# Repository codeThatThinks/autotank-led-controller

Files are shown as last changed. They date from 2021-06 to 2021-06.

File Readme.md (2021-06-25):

# autotank-led-hw

A CANbus-enabled LED and GPIO controller -- PCB design files

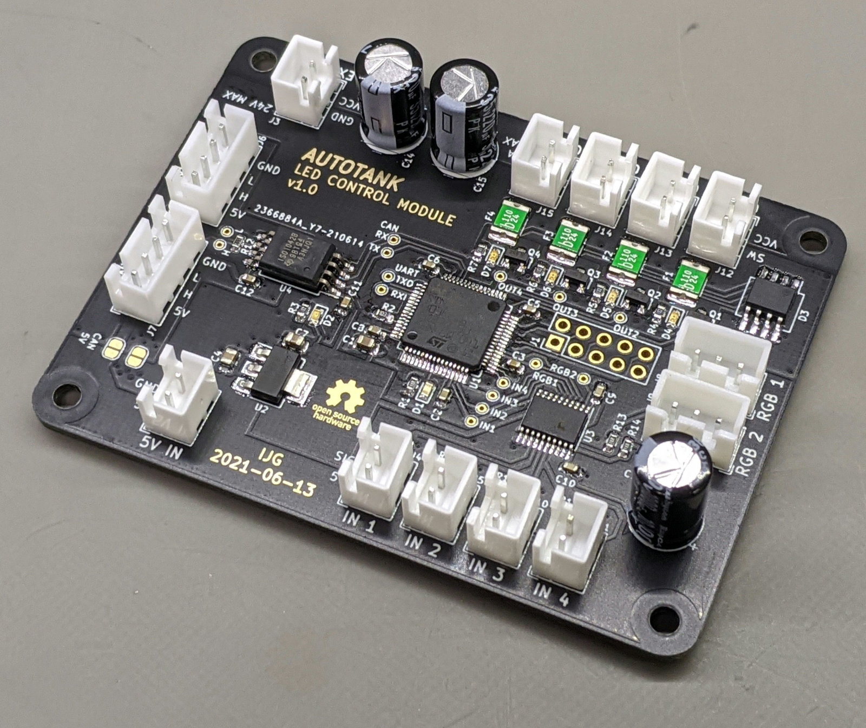
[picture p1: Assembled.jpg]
Assembled PCB


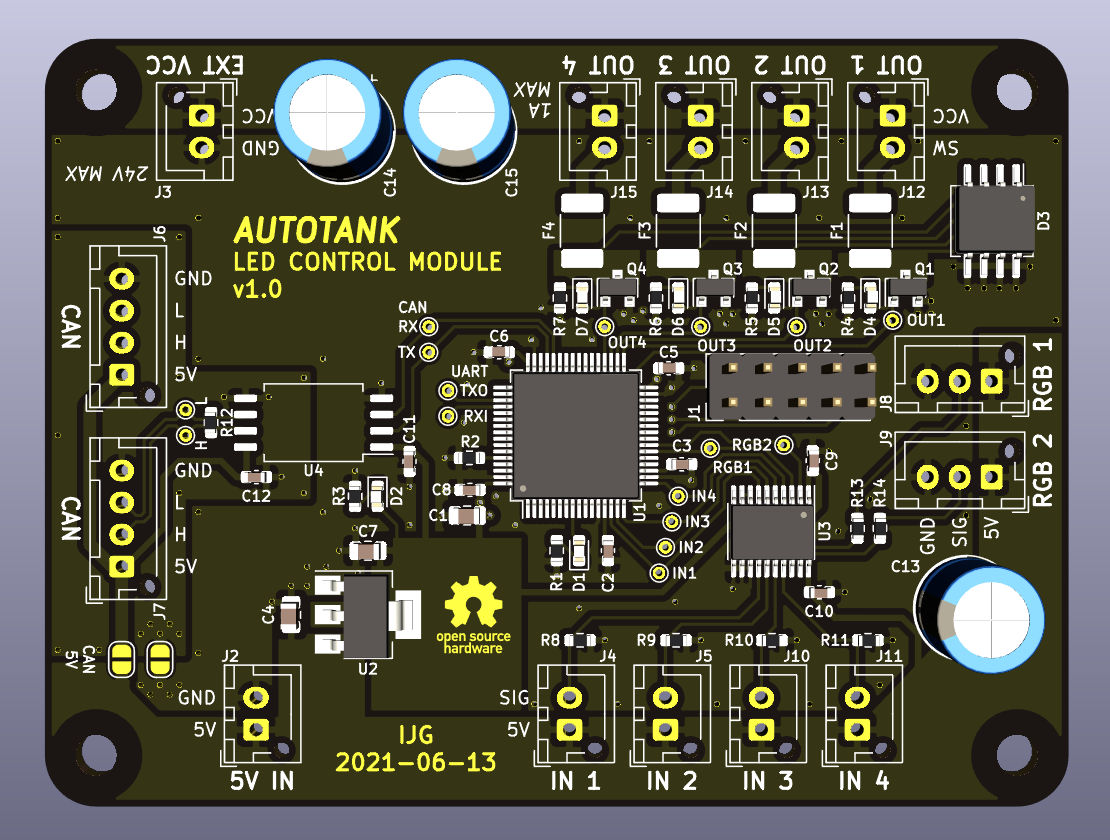
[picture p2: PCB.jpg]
PCB Render


## Theory of Operation

The controller listens for messages on the CANbus and drives two addressable RGB LED strips and four general-purpose open-collector outputs. It also monitors four general-purpose inputs and can send CANbus messages or change outputs in response to events.

The outputs are rated for 1A each and are intended to drive LED lights, such as headlights, tail lights, etc. The inputs are active-high and intended for body sensors and switches, such as a door switch.

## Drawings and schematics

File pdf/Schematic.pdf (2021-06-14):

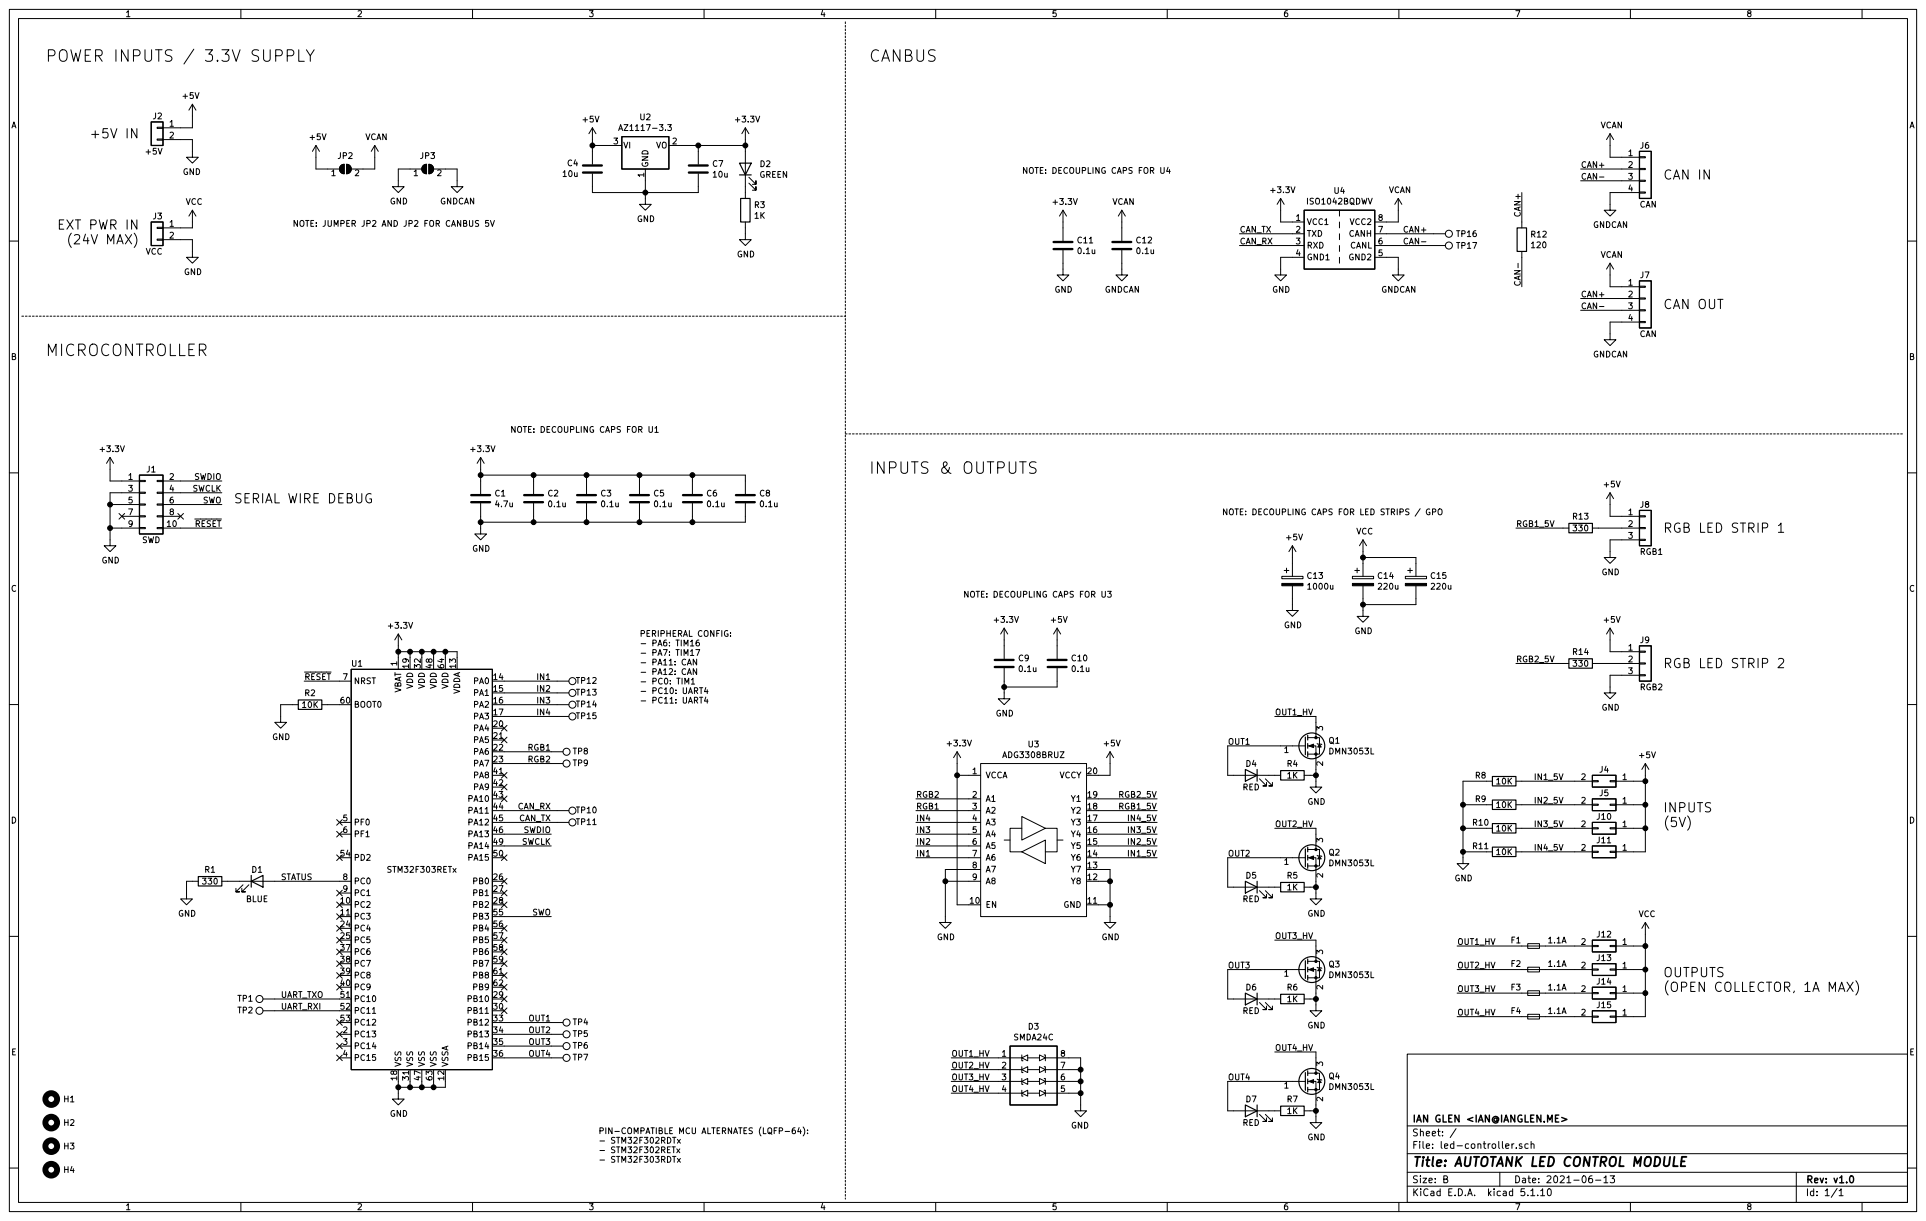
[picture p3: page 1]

NOTE: DECOUPLING CAPS FOR LED STRIPS / GPO POWER INPUTS / 3.3V SUPPLY

NOTE: DECOUPLING CAPS FOR U4 CANBUS
0.1u GND

1 VDD 19 VDD 32 VDD 48 VDD 64 VDDA 13 VSS 18 VSS 31 VSS 47 VSS 63 VSSA 12 U1 STM32F303RETx +3.3V

IAN GLEN <IAN@IANGLEN.ME> GND

File: led-controller.sch Sheet: /
Id: 1/1 Title: AUTOTANK LED CONTROL MODULE

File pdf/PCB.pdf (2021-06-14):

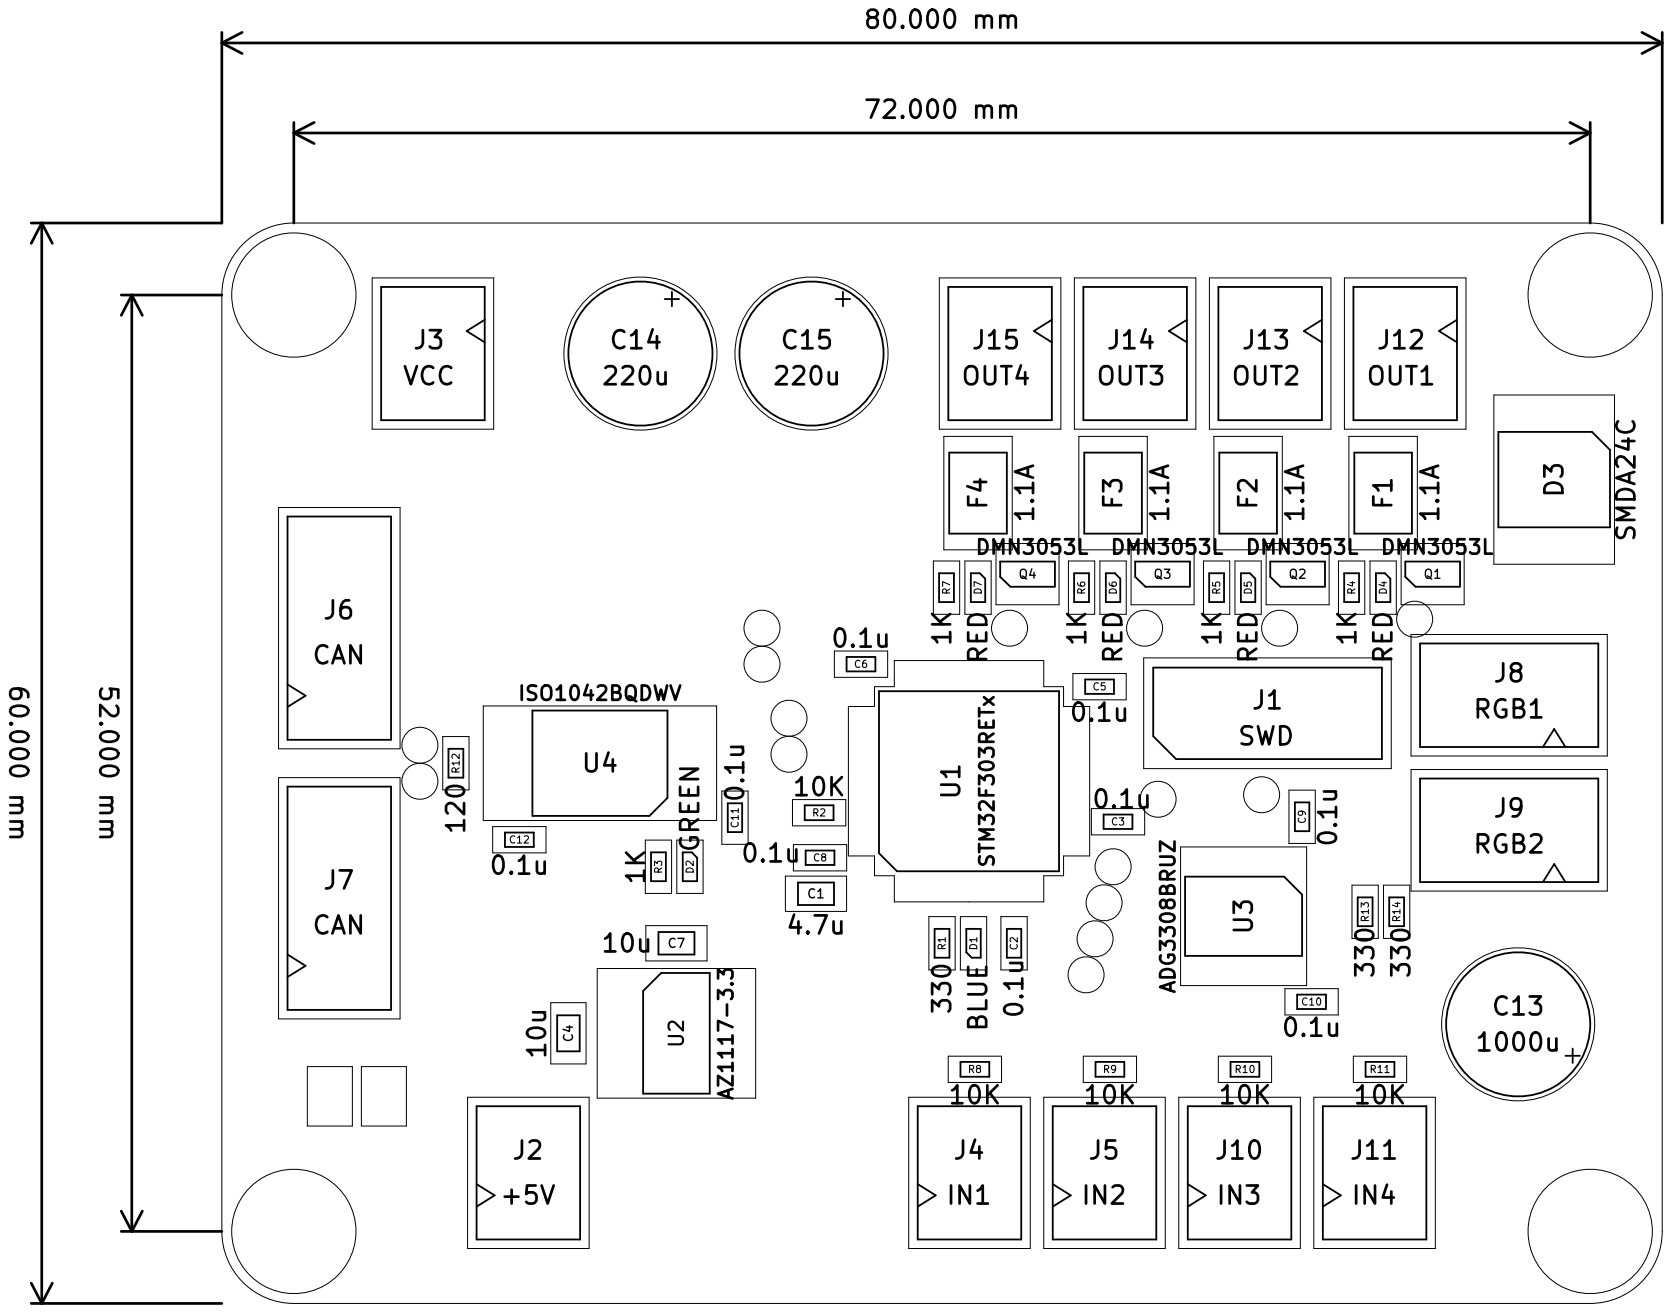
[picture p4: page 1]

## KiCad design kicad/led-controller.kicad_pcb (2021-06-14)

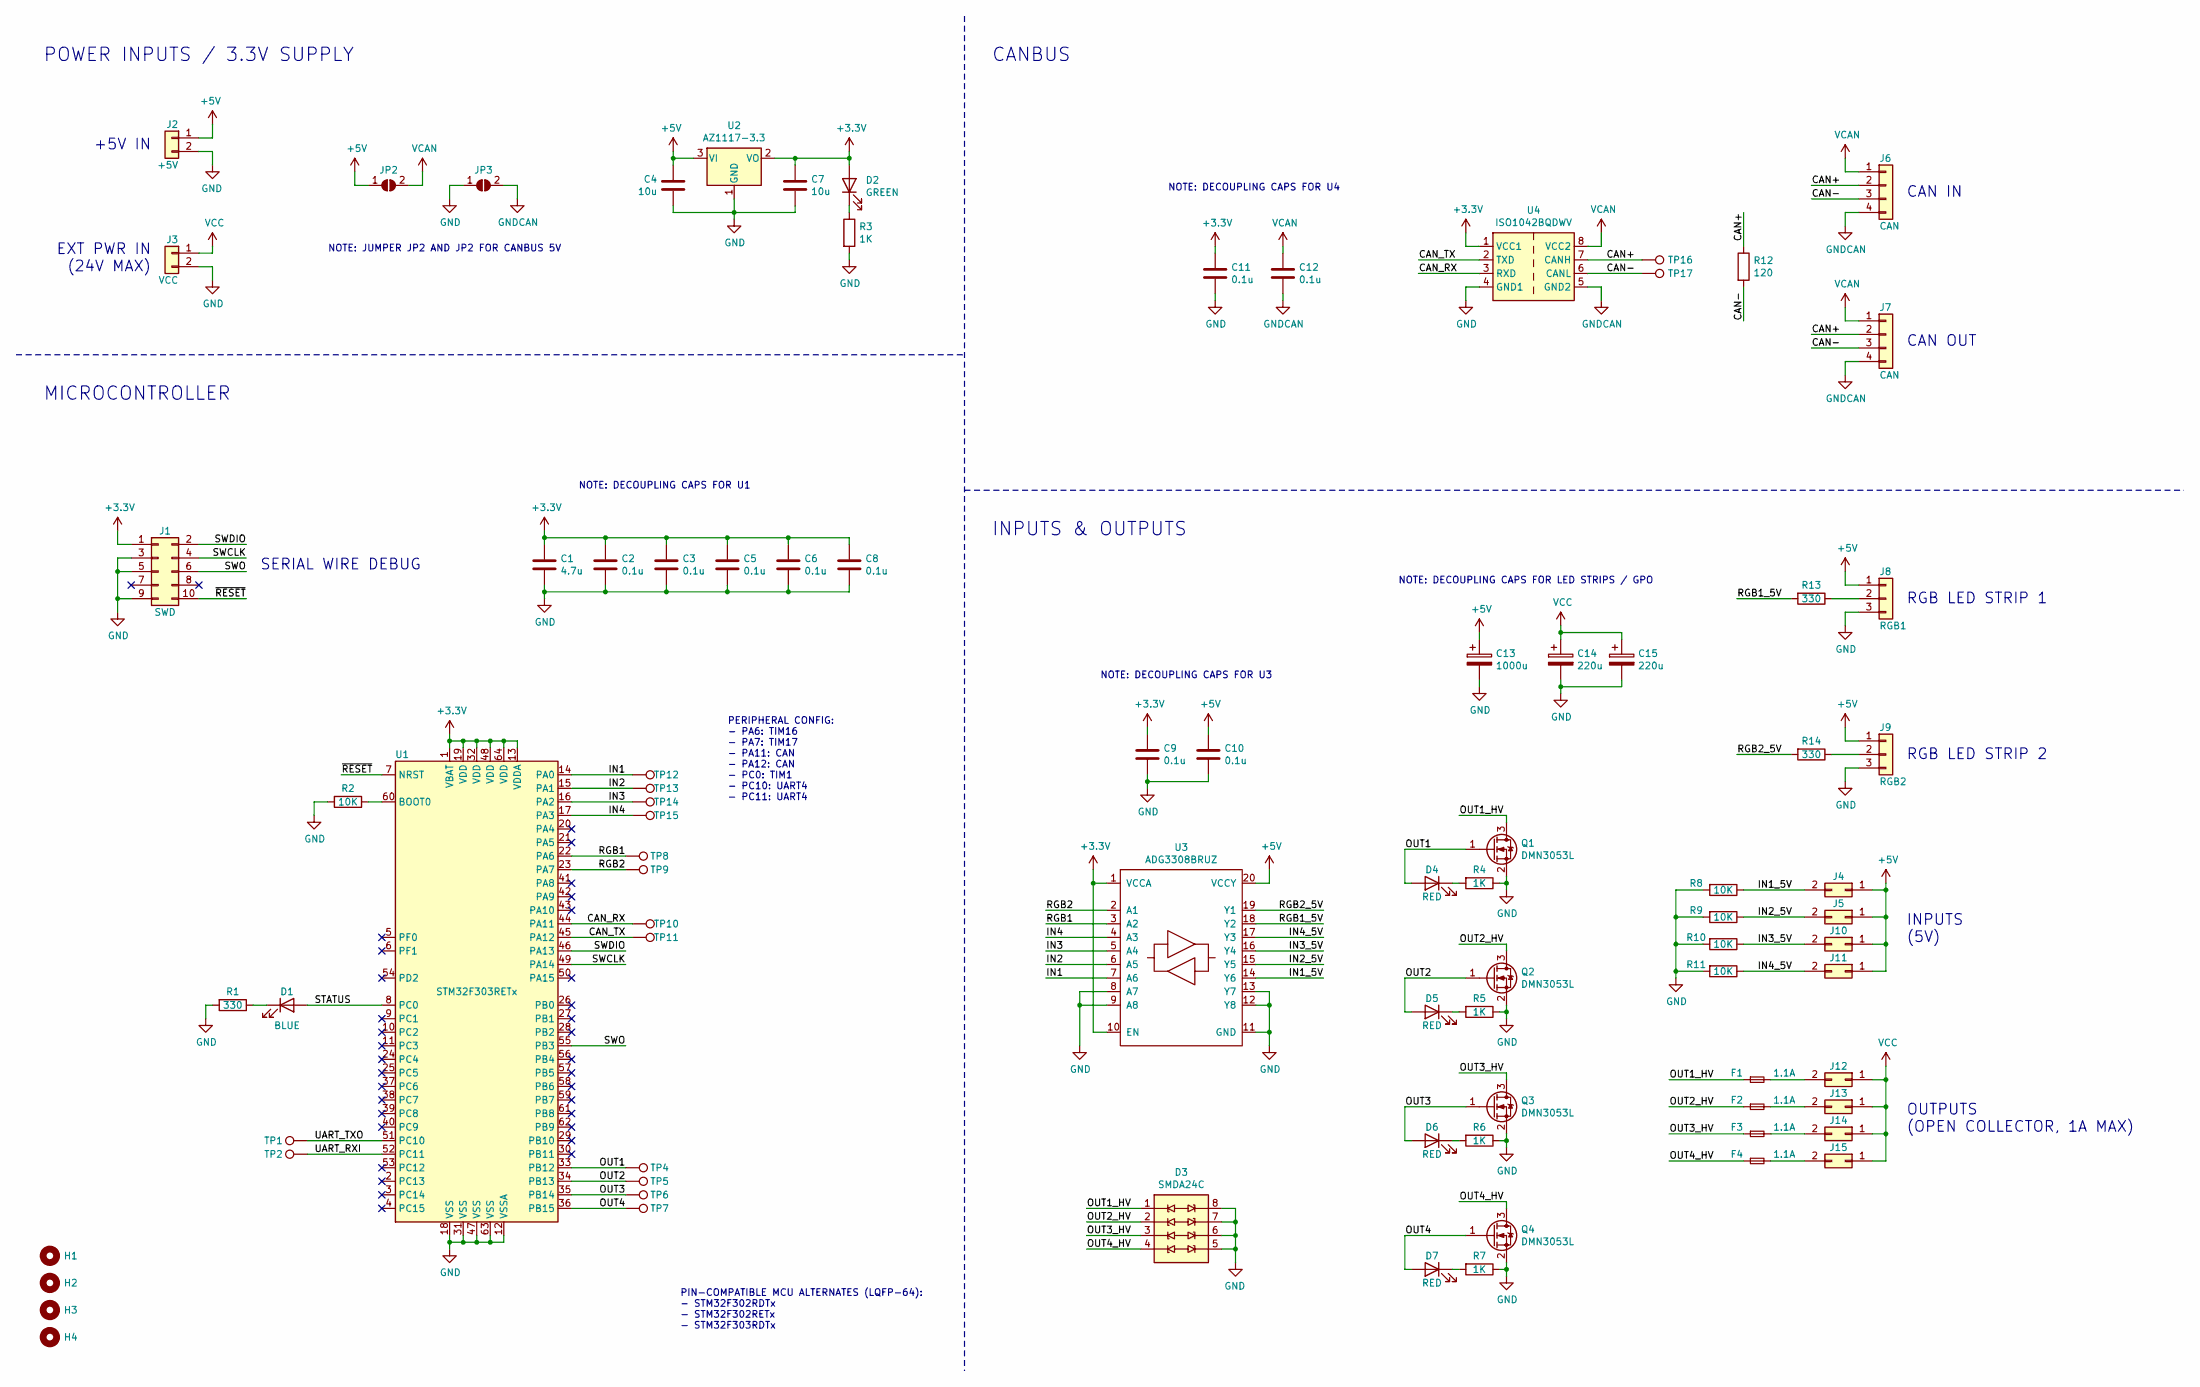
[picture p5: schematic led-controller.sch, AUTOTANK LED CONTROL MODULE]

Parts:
C1: 4.7u; C_0805_2012Metric
C2, C3, C5, C6, C8, C9, C10, C11, C12: 0.1u; C_0603_1608Metric
C4, C7: 10u; C_0805_2012Metric
C13: 1000u; CP_Radial_D8.0mm_P3.50mm
C14, C15: 220u; CP_Radial_D8.0mm_P3.50mm
D1: BLUE; LED_0603_1608Metric
D2: GREEN; LED_0603_1608Metric
D3: SMDA24C; SO-8_5.3x6.2mm_P1.27mm
D4, D5, D6, D7: RED; LED_0603_1608Metric
F1, F2, F3, F4: 1.1A; Fuse_1812_4532Metric_Castellated
H1, H2, H3, H4: MountingHole; MountingHole_3.2mm_M3
J1: SWD; PinHeader_2x05_P2.54mm_Vertical
J2: +5V; JST_XH_B2B-XH-AM_1x02_P2.50mm_Vertical
J3: VCC; JST_XH_B2B-XH-AM_1x02_P2.50mm_Vertical
J4: IN1; JST_XH_B2B-XH-AM_1x02_P2.50mm_Vertical
J5: IN2; JST_XH_B2B-XH-AM_1x02_P2.50mm_Vertical
J6, J7: CAN; JST_XH_B4B-XH-AM_1x04_P2.50mm_Vertical
J8: RGB1; JST_XH_B3B-XH-AM_1x03_P2.50mm_Vertical
J9: RGB2; JST_XH_B3B-XH-AM_1x03_P2.50mm_Vertical
J10: IN3; JST_XH_B2B-XH-AM_1x02_P2.50mm_Vertical
J11: IN4; JST_XH_B2B-XH-AM_1x02_P2.50mm_Vertical
J12: OUT1; JST_XH_B2B-XH-AM_1x02_P2.50mm_Vertical
J13: OUT2; JST_XH_B2B-XH-AM_1x02_P2.50mm_Vertical
J14: OUT3; JST_XH_B2B-XH-AM_1x02_P2.50mm_Vertical
J15: OUT4; JST_XH_B2B-XH-AM_1x02_P2.50mm_Vertical
JP2, JP3: SolderJumper_2_Open; SolderJumper-2_P1.3mm_Open_RoundedPad1.0x1.5mm
Q1, Q2, Q3, Q4: DMN3053L; SOT-23
R1, R13, R14: 330; R_0603_1608Metric
R2, R8, R9, R10, R11: 10K; R_0603_1608Metric
R3, R4, R5, R6, R7: 1K; R_0603_1608Metric
R12: 120; R_0603_1608Metric
TP1: TXO; TestPoint_THTPad_D1.0mm_Drill0.5mm
TP2: RXI; TestPoint_THTPad_D1.0mm_Drill0.5mm
TP4: OUT1; TestPoint_THTPad_D1.0mm_Drill0.5mm
TP5: OUT2; TestPoint_THTPad_D1.0mm_Drill0.5mm
TP6: OUT3; TestPoint_THTPad_D1.0mm_Drill0.5mm
TP7: OUT4; TestPoint_THTPad_D1.0mm_Drill0.5mm
TP8: RGB1; TestPoint_THTPad_D1.0mm_Drill0.5mm
TP9: RGB2; TestPoint_THTPad_D1.0mm_Drill0.5mm
TP10: RX; TestPoint_THTPad_D1.0mm_Drill0.5mm
TP11: TX; TestPoint_THTPad_D1.0mm_Drill0.5mm
TP12: IN1; TestPoint_THTPad_D1.0mm_Drill0.5mm
TP13: IN2; TestPoint_THTPad_D1.0mm_Drill0.5mm
TP14: IN3; TestPoint_THTPad_D1.0mm_Drill0.5mm
TP15: IN4; TestPoint_THTPad_D1.0mm_Drill0.5mm
TP16: H; TestPoint_THTPad_D1.0mm_Drill0.5mm
TP17: L; TestPoint_THTPad_D1.0mm_Drill0.5mm
U1: STM32F303RETx; LQFP-64_10x10mm_P0.5mm
U2: AZ1117-3.3; SOT-223-3_TabPin2
U3: ADG3308BRUZ; TSSOP-20_4.4x6.5mm_P0.65mm
U4: ISO1042BQDWV; SOIC-8_7.5x5.85mm_P1.27mm

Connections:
+3V3: C1.1, C2.1, C3.1, C5.1, C6.1, C7.1, C8.1, C9.1, C11.1, D2.2 (A), J1.1, U1.1 (VBAT), U1.13 (VDDA), U1.19 (VDD), U1.32 (VDD), U1.48 (VDD), U1.64 (VDD), U2.2 (VO), U3.1 (VCCA), U3.10 (EN), U4.1 (VCC1)
+5V: C4.2, C10.1, C13.1, J2.1, J4.1, J5.1, J8.1, J9.1, J10.1, J11.1, JP2.1 (A), U2.3 (VI), U3.20 (VCCY)
/CAN+: J6.2, J7.2, R12.1, TP16.1, U4.7 (CANH)
/CAN-: J6.3, J7.3, R12.2, TP17.1, U4.6 (CANL)
/CAN_RX: TP10.1, U1.44 (PA11), U4.3 (RXD)
/CAN_TX: TP11.1, U1.45 (PA12), U4.2 (TXD)
/IN1: TP12.1, U1.14 (PA0), U3.7 (A6)
/IN1_5V: J4.2, R8.1, U3.14 (Y6)
/IN2: TP13.1, U1.15 (PA1), U3.6 (A5)
/IN2_5V: J5.2, R9.1, U3.15 (Y5)
/IN3: TP14.1, U1.16 (PA2), U3.5 (A4)
/IN3_5V: J10.2, R10.1, U3.16 (Y4)
/IN4: TP15.1, U1.17 (PA3), U3.4 (A3)
/IN4_5V: J11.2, R11.1, U3.17 (Y3)
/OUT1: D4.2 (A), Q1.1 (G), TP4.1, U1.33 (PB12)
/OUT1_HV: D3.1 (TVS1A), F1.1, Q1.3 (D)
/OUT2: D5.2 (A), Q2.1 (G), TP5.1, U1.34 (PB13)
/OUT2_HV: D3.2 (TVS2A), F2.1, Q2.3 (D)
/OUT3: D6.2 (A), Q3.1 (G), TP6.1, U1.35 (PB14)
/OUT3_HV: D3.3 (TVS3A), F3.1, Q3.3 (D)
/OUT4: D7.2 (A), Q4.1 (G), TP7.1, U1.36 (PB15)
/OUT4_HV: D3.4 (TVS4A), F4.1, Q4.3 (D)
/RGB1: TP8.1, U1.22 (PA6), U3.3 (A2)
/RGB1_5V: R13.2, U3.18 (Y2)
/RGB2: TP9.1, U1.23 (PA7), U3.2 (A1)
/RGB2_5V: R14.2, U3.19 (Y1)
/STATUS: D1.2 (A), U1.8 (PC0)
/SWCLK: J1.4, U1.49 (PA14)
/SWDIO: J1.2, U1.46 (PA13)
/SWO: J1.6, U1.55 (PB3)
/UART_RXI: TP2.1, U1.52 (PC11)
/UART_TXO: TP1.1, U1.51 (PC10)
/~RESET: J1.10, U1.7 (NRST)
GND: C1.2, C2.2, C3.2, C4.1, C5.2, C6.2, C7.2, C8.2, C9.2, C10.2, C11.2, C13.2, C14.2, C15.2, D3.5 (TVS4B), D3.6 (TVS3B), D3.7 (TVS2B), D3.8 (TVS1A), J1.3, J1.5, J1.9, J2.2, J3.2, J8.3, J9.3, JP3.1 (A), Q1.2 (S), Q2.2 (S), Q3.2 (S), Q4.2 (S), R1.2, R2.2, R3.2, R4.1, R5.1, R6.1, R7.1, R8.2, R9.2, R10.2, R11.2, U1.12 (VSSA), U1.18 (VSS), U1.31 (VSS), U1.47 (VSS), U1.63 (VSS), U2.1 (GND), U3.8 (A7), U3.9 (A8), U3.11 (GND), U3.12 (Y8), U3.13 (Y7), U4.4 (GND1)
GNDCAN: C12.2, J6.4, J7.4, JP3.2 (B), U4.5 (GND2)
unnamed: D1.1 (K), R1.1
unnamed: D2.1 (K), R3.1
unnamed: D4.1 (K), R4.2
unnamed: D5.1 (K), R5.2
unnamed: D6.1 (K), R6.2
unnamed: D7.1 (K), R7.2
unnamed: F1.2, J12.2
unnamed: F2.2, J13.2
unnamed: F3.2, J14.2
unnamed: F4.2, J15.2
unnamed: J8.2, R13.1
unnamed: J9.2, R14.1
unnamed: R2.1, U1.60 (BOOT0)
VCAN: C12.1, J6.1, J7.1, JP2.2 (B), U4.8 (VCC2)
VCC: C14.1, C15.1, J3.1, J12.1, J13.1, J14.1, J15.1

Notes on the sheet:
SERIAL WIRE DEBUG
CAN IN
CAN OUT
POWER INPUTS / 3.3V SUPPLY
MICROCONTROLLER
CANBUS
INPUTS & OUTPUTS
NOTE: DECOUPLING CAPS FOR U4
+5V IN
RGB LED STRIP 1
RGB LED STRIP 2
NOTE: DECOUPLING CAPS FOR U3
NOTE: DECOUPLING CAPS FOR U1
PIN-COMPATIBLE MCU ALTERNATES (LQFP-64): - STM32F302RDTx - STM32F302RETx - STM32F303RDTx
PERIPHERAL CONFIG: - PA6: TIM16 - PA7: TIM17 - PA11: CAN - PA12: CAN - PC0: TIM1 - PC10: UART4 - PC11: UART4
INPUTS (5V)
OUTPUTS (OPEN COLLECTOR, 1A MAX)
NOTE: DECOUPLING CAPS FOR LED STRIPS / GPO
NOTE: JUMPER JP2 AND JP2 FOR CANBUS 5V
EXT PWR IN (24V MAX)

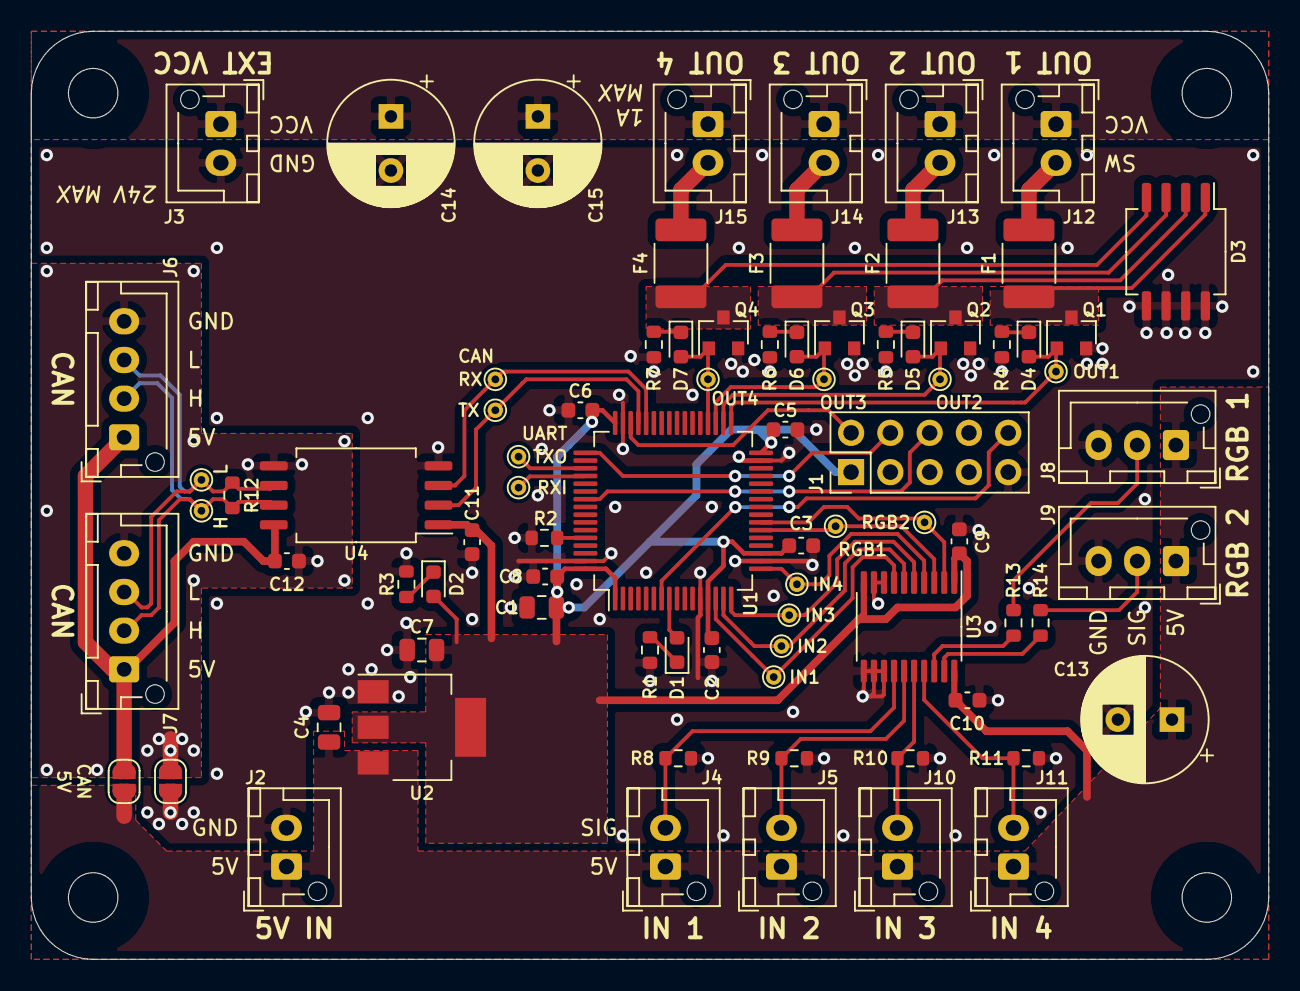
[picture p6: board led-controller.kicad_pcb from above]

Board: 2 copper layers, 80.0 x 60.0 mm, 85 parts (0 on the bottom side), 50 nets.

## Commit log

2021-06-25 Add interactive BOM; move assembly files to own folder
2021-06-25 Add photo of assembled PCB
